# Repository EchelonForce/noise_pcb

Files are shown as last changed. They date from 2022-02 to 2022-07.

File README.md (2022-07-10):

# Noise PCB

This is a PCB for a Eurorack noise synth module which hosts a Electric Druid Noise2 chip.

Full writeup here: https://www.robotdialogs.com/2022/07/eurorack-noise-generator-v1.html

This work is licensed under a Creative Commons Attribution-NonCommercial-ShareAlike 4.0 International License. https://creativecommons.org/licenses/by-nc-sa/4.0/

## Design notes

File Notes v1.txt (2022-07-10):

Assembly Order
 - Surface Mount Resistors
 - Ceramic caps first, the solder points are below sockets on the top side.
 - IC Sockets
 - Diodes and Ferrite Beads
 - Polarized Caps
 - 2x5 Socket
 - 7805 Regulator
 - Jacks, aligned to panel.

V1 (with 1k buffer resistors) Current Draw:
 +12V Rail, 21mA
 -12V Rail, 7mA

V2 changes to make:
 - Use better footprint for polarized caps.
 - Fix missing cap values - done.
 - Fix Gain of inverted filtered white noise, it's -1 it should be -2 to get actual inversion of other output.
 - Change all the resistors on buffers to 10k or 100k to reduce current. - done
 - Add alternate 7805 footprint for T0-92 or surface mount.

Front Panel Notes. 
Inverted filt on v2 is 0:-10V not 0:10V -fixed in latest

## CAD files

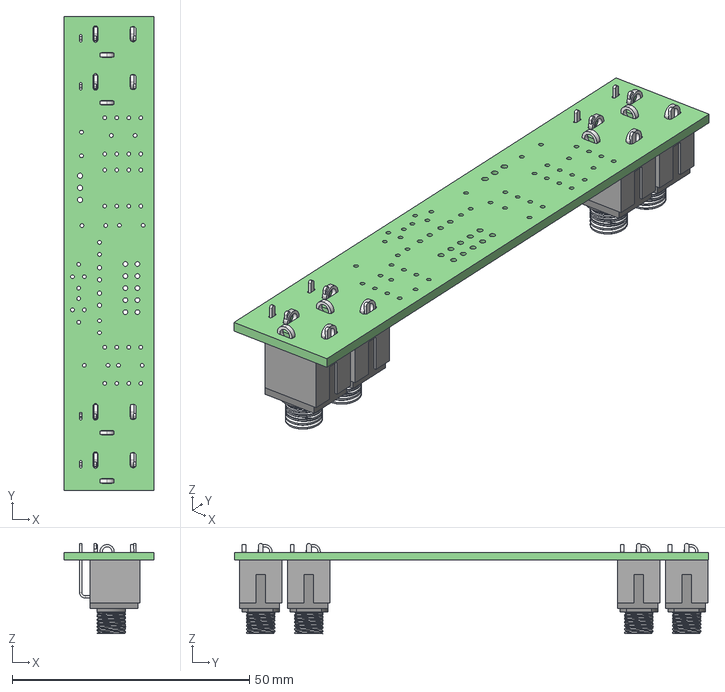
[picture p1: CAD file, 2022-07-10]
noise_pcb.step
19.0 x 100.0 x 19.1 mm
noise_pcb PCB

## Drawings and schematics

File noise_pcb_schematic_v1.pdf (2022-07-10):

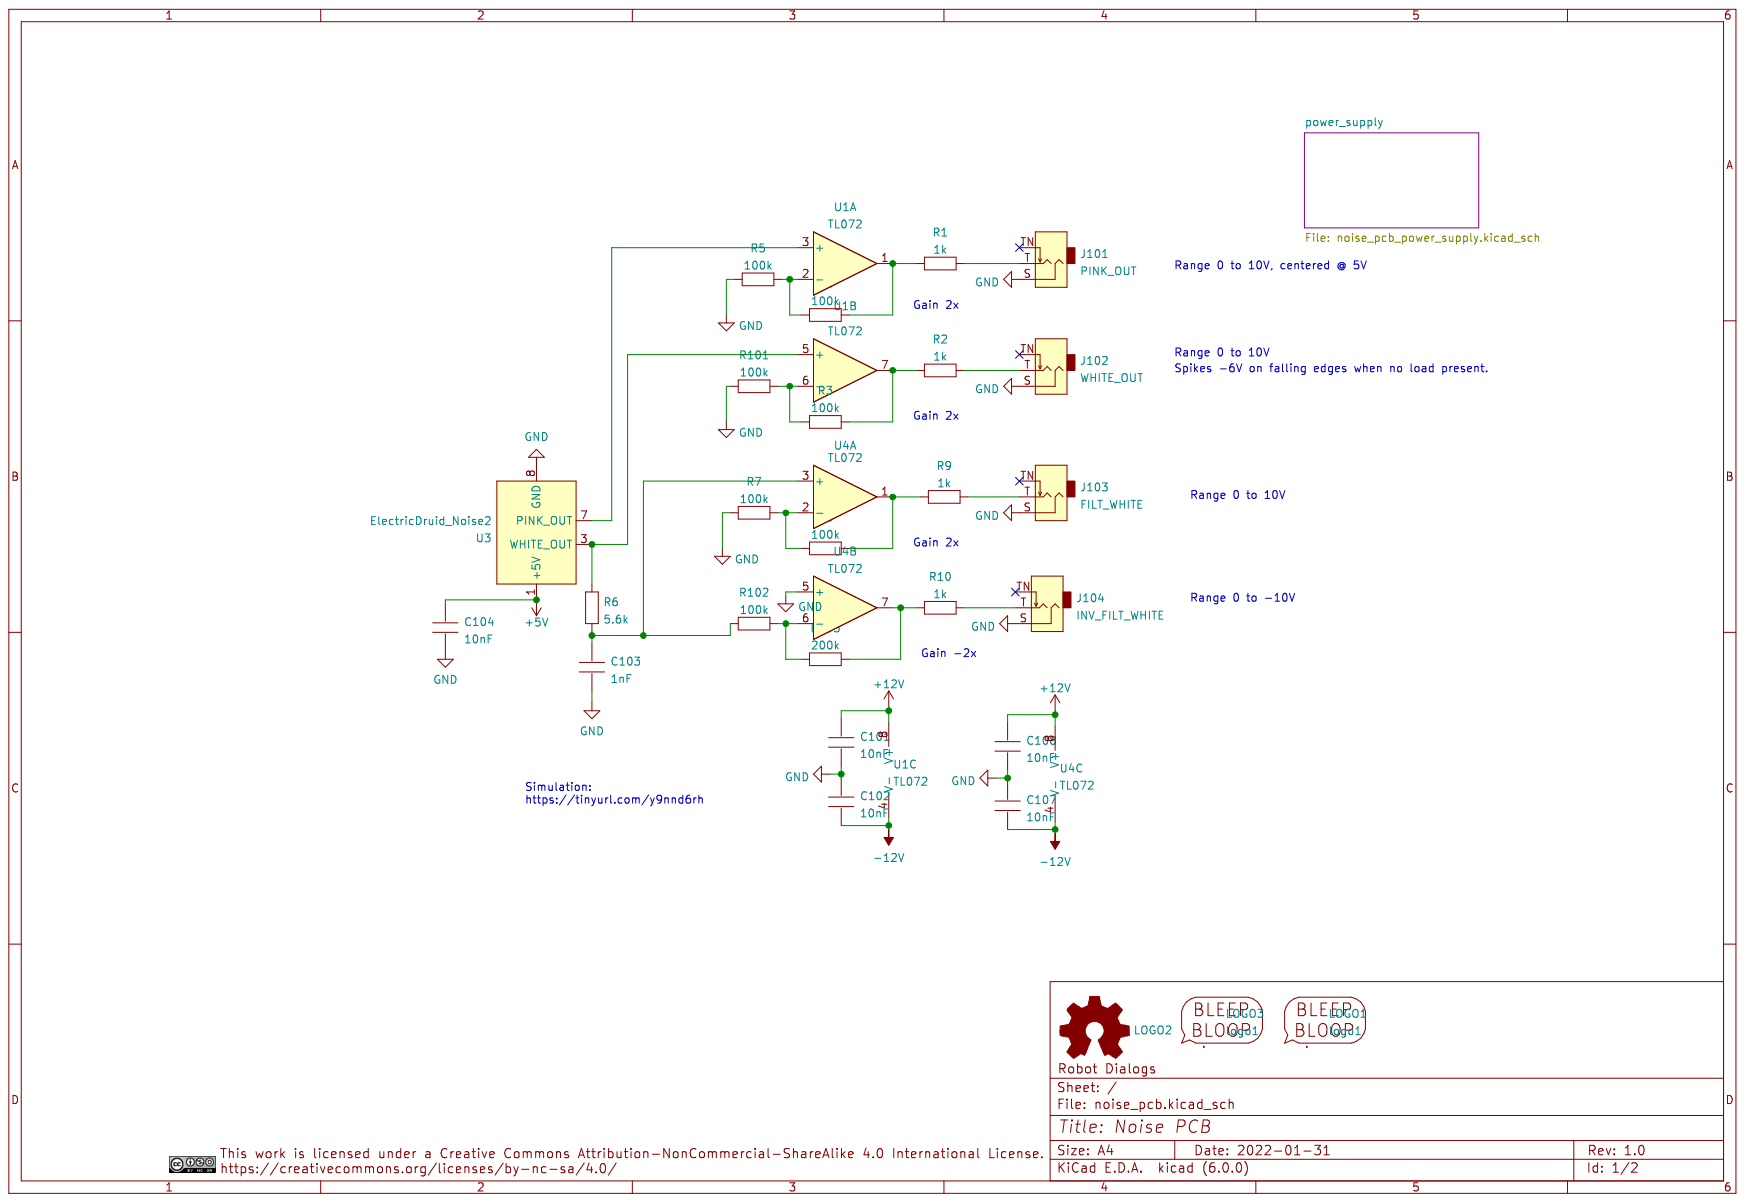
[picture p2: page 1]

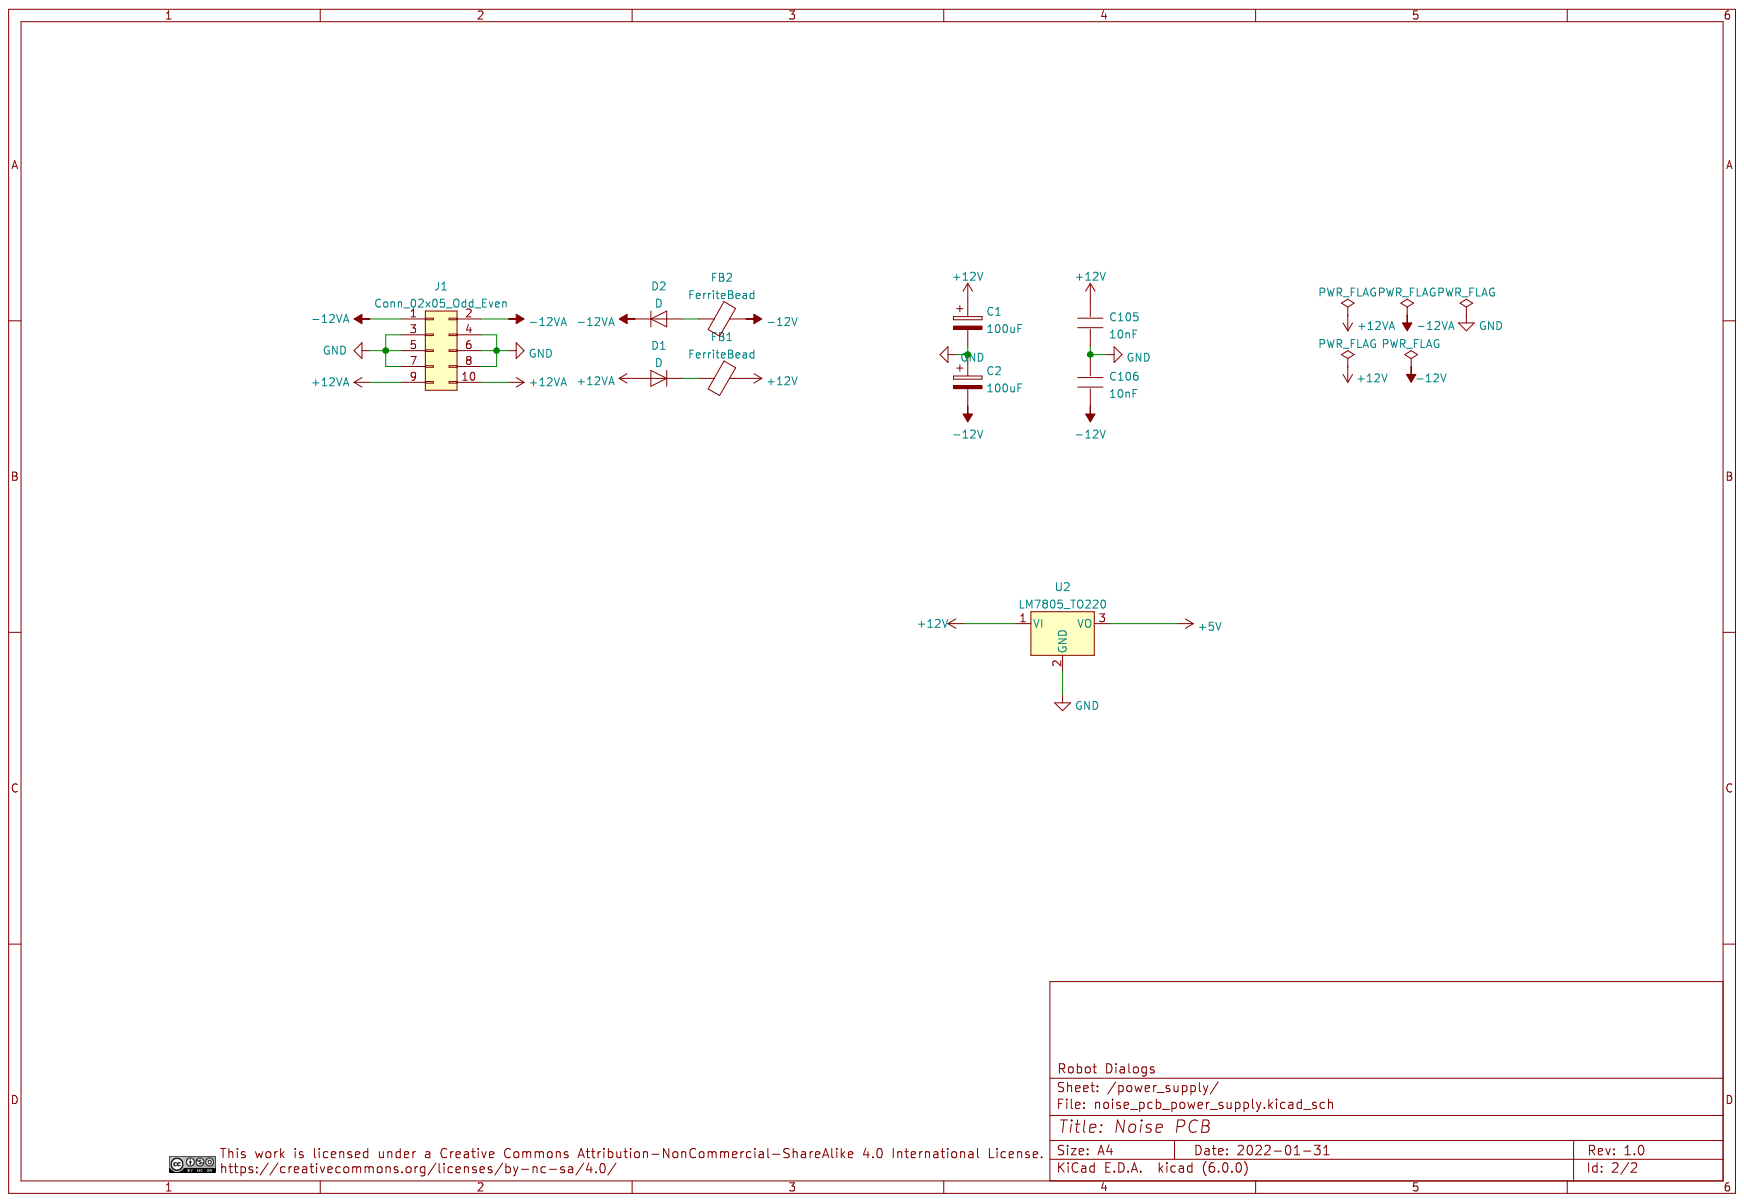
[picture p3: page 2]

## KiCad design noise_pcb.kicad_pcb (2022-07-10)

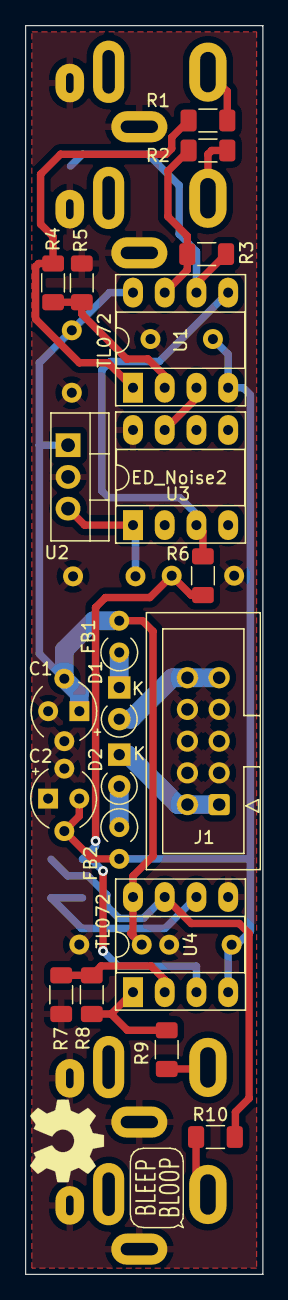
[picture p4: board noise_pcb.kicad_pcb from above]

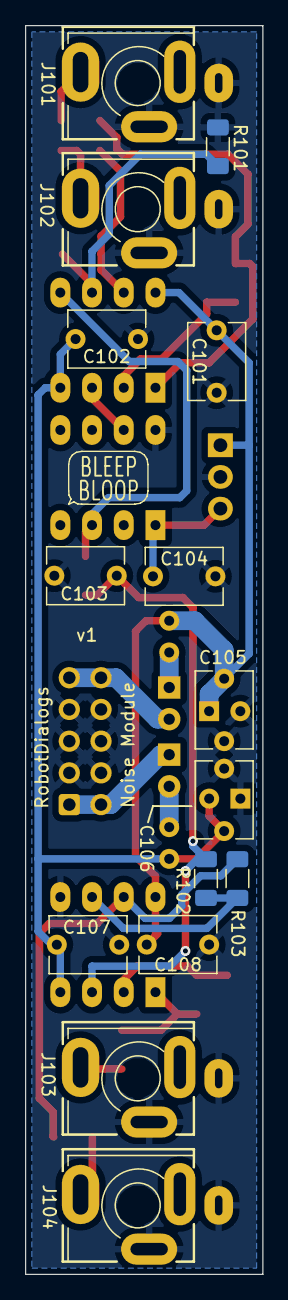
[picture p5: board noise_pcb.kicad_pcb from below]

Board: 2 copper layers, 19.0 x 100.0 mm, 39 parts (15 on the bottom side), 23 nets.

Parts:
C1, C2: 100uF; CP_Radial_D5.0mm_P2.50mm
C101, C102, C107, C108: C; C_Disc_D6.0mm_W4.4mm_P5.00mm
C103: 1nF; C_Disc_D6.0mm_W4.4mm_P5.00mm
C104, C105, C106: 10nF; C_Disc_D6.0mm_W4.4mm_P5.00mm
D1, D2: D; D_A-405_P2.54mm_Vertical_KathodeUp
FB1, FB2: FerriteBead; L_Axial_L6.6mm_D2.7mm_P2.54mm_Vertical_Vishay_IM-2
J1: Conn_02x05_Odd_Even; IDC-Header_2x05_P2.54mm_Vertical
J101: PINK_OUT; Jack_3.5mm_MJ-355W_and_PJ398SM_Vertical
J102: WHITE_OUT; Jack_3.5mm_MJ-355W_and_PJ398SM_Vertical
J103: FILT_WHITE; Jack_3.5mm_MJ-355W_and_PJ398SM_Vertical
J104: INV_FILT_WHITE; Jack_3.5mm_MJ-355W_and_PJ398SM_Vertical
LOGO1: logo1; Logo2
LOGO2: Logo_Open_Hardware_Small; OSHW-Symbol_6.7x6mm_SilkScreen
LOGO3: logo1; Logo1
R1, R2, R3, R4, R5, R7, R8, R9, R10, R101: 1k; R_1206_3216Metric_Pad1.30x1.75mm_HandSolder
R6: 5.6k; R_1206_3216Metric_Pad1.30x1.75mm_HandSolder
R102, R103: 100k; R_1206_3216Metric_Pad1.30x1.75mm_HandSolder
U1, U4: TL072; DIP-8_W7.62mm_Socket_LongPads
U2: LM7805_TO220; TO-220-3_Vertical
U3: ElectricDruid_Noise2; DIP-8_W7.62mm_Socket_LongPads

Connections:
+5V: C104.1, U2.3 (VO), U3.1 (+5V)
+12V: C1.1, C101.1, C105.1, C108.1, FB1.2, U1.8 (V+), U2.1 (VI), U4.8 (V+)
+12VA: D1.2 (A), J1.9, J1.10
-12V: C2.2, C102.2, C106.2, C107.2, FB2.2, U1.4 (V-), U4.4 (V-)
-12VA: D2.1 (K), J1.1, J1.2
GND: C1.2, C2.1, C101.2, C102.1, C103.2, C104.2, C105.2, C106.1, C107.1, C108.2, J1.3, J1.4, J1.5, J1.6, J1.7, J1.8, J101.S, J102.S, J103.S, J104.S, R5.1, R7.1, R101.1, U2.2 (GND), U3.8 (GND), U4.5 (+)
unnamed: C103.1, R6.1, R102.1, U4.3 (+)
unnamed: D1.1 (K), FB1.1
unnamed: D2.2 (A), FB2.1
unnamed: J101.T, R1.2
unnamed: J102.T, R2.2
unnamed: J103.T, R9.2
unnamed: J104.T, R10.2
unnamed: R1.1, R4.2, U1.1
unnamed: R3.1, R101.2, U1.6 (-)
unnamed: R2.1, R3.2, U1.7
unnamed: R4.1, R5.2, U1.2 (-)
unnamed: R6.2, U1.5 (+), U3.3 (WHITE_OUT)
unnamed: R7.2, R8.1, U4.2 (-)
unnamed: R8.2, R9.1, U4.1
unnamed: R102.2, R103.1, U4.6 (-)
unnamed: R10.1, R103.2, U4.7
unnamed: U1.3 (+), U3.7 (PINK_OUT)

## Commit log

2022-02-19 Version 1.0 as ordered
    [noise_pcb.kicad_pcb, noise_pcb.kicad_sch, noise_pcb_panelized.kicad_pcb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]
2022-07-10 Assembly notes, value fixes, README
    [noise_pcb.kicad_pcb, noise_pcb.kicad_sch, noise_pcb.step]
2022-07-10 Title block updates and pdf
    [noise_pcb.kicad_pcb, noise_pcb.kicad_sch, noise_pcb_power_supply.kicad_sch]
